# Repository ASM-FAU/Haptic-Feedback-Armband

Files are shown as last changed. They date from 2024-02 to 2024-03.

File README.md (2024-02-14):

# Haptic Feedback Armband

The haptic feedback armband was mainly designed for prosthesis appliacations. It contains 5 vibration motors, of which each can correspond to one finger. The device is completely wireless and contains a custom designed PCB, 1800 mAh lithium polymer battery, 5 vibration motors, an IMU to gather motion data and an FSR to measure armband tightness. All code and hardware models are provided in this repository to replicate the device.

## Software
The software is split into two parts for the client device (the haptic feedback armband) and a master PC that it communicates with. The architecture is shown in the follong Figure.
Ros_overview

## Hardware
The armband consists of 5 modules in total. A main module, containing the PCB, battery and senors as well as a vibration motor and smaller modules containing a vibration motor only. The casing was 3D printed using FDM and PLA filament. The flexible links were printed with TPU filament. This is how the armband looks like:
Armband_3D_View
main_module
sub_module

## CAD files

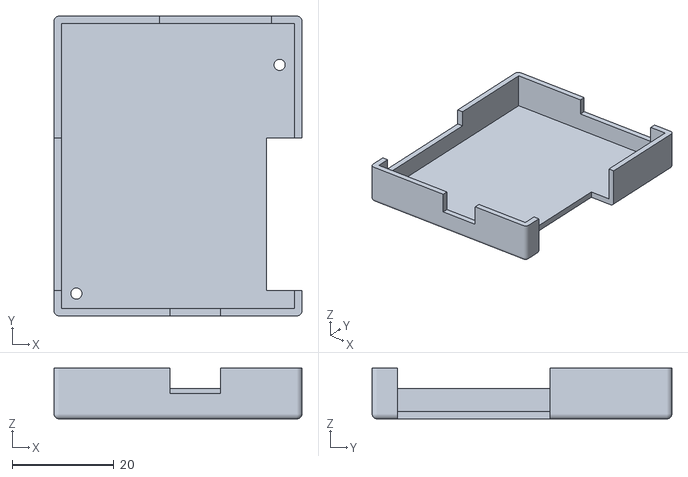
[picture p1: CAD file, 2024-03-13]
CAD/Main_Cover.stl
48.8 x 59.0 x 10.0

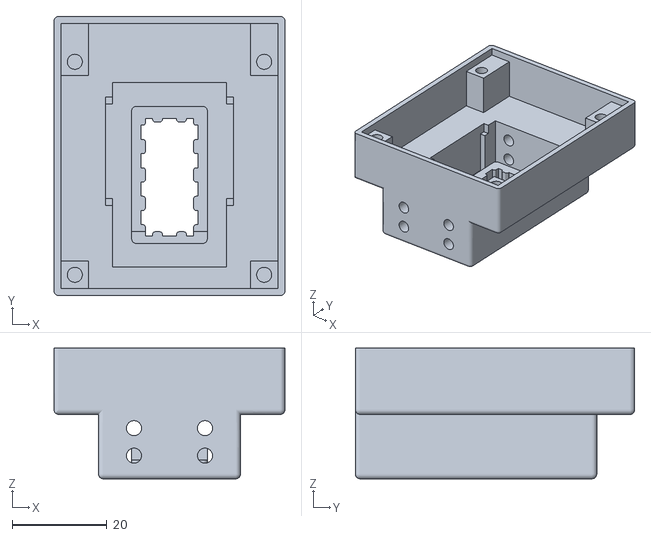
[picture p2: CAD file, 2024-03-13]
CAD/Main_Case.stl
48.8 x 59.0 x 27.6

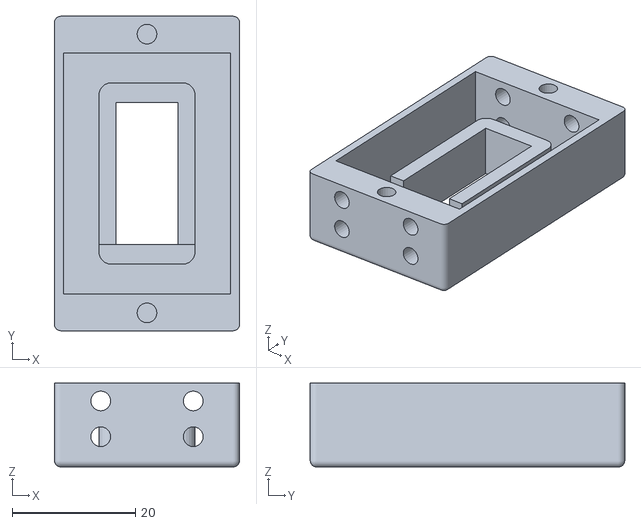
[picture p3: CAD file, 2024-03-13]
CAD/Sub_Case.stl
30.0 x 51.0 x 13.6

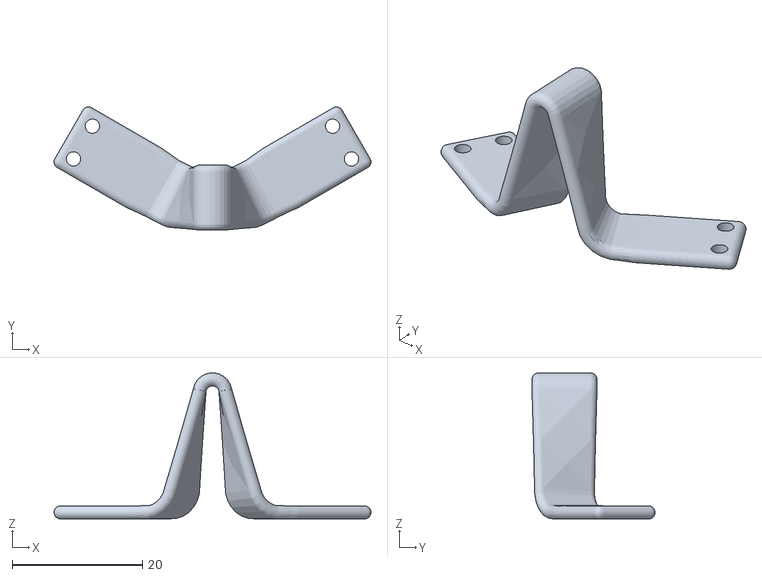
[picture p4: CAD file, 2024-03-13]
CAD/Link_Medium.stl
48.7 x 18.9 x 22.4

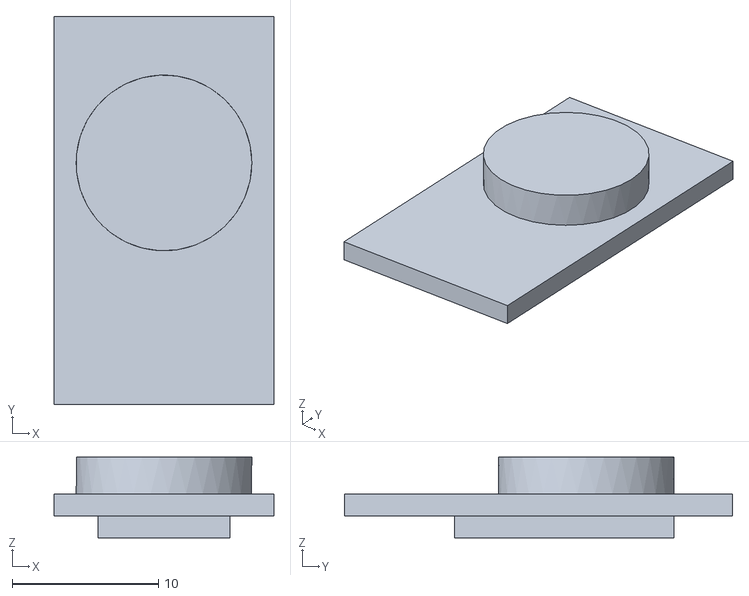
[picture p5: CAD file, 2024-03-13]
CAD/Force_Transmitter.stl
15.0 x 26.5 x 5.50

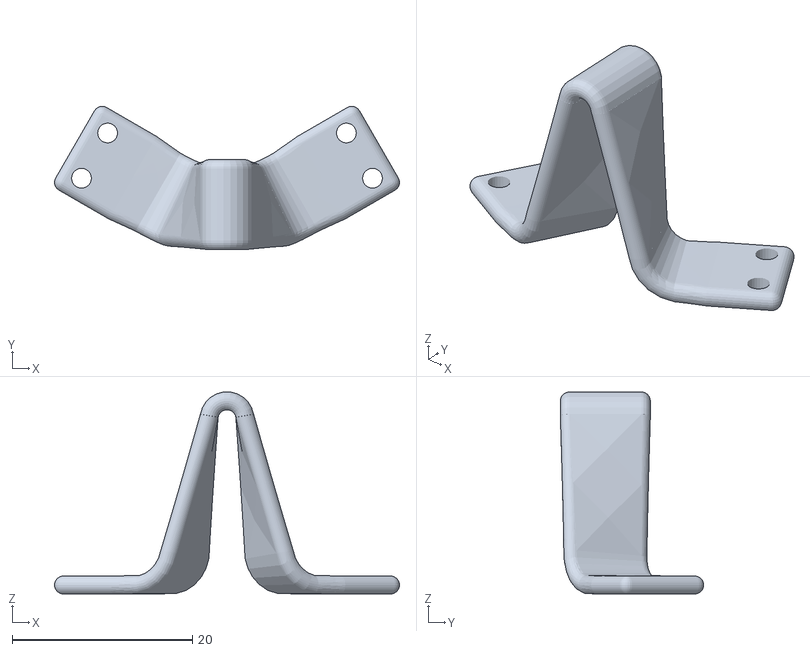
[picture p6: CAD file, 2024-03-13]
CAD/Link_Small.stl
38.3 x 15.9 x 22.4

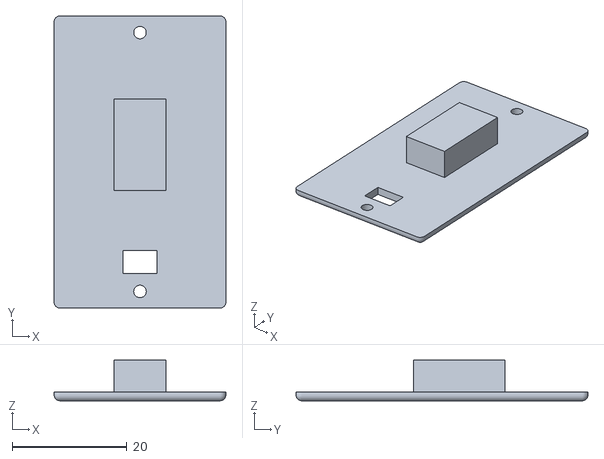
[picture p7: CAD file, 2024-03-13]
CAD/Sub_Cover.stl
30.0 x 51.0 x 7.10

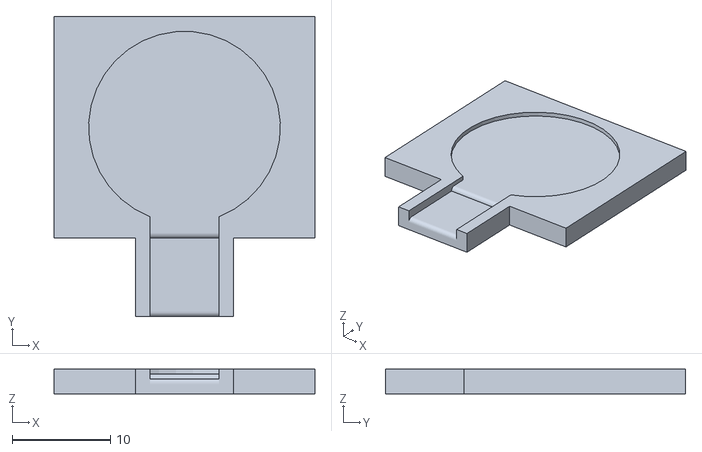
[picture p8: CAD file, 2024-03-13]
CAD/FSR_Support.stl
26.5 x 30.5 x 2.50

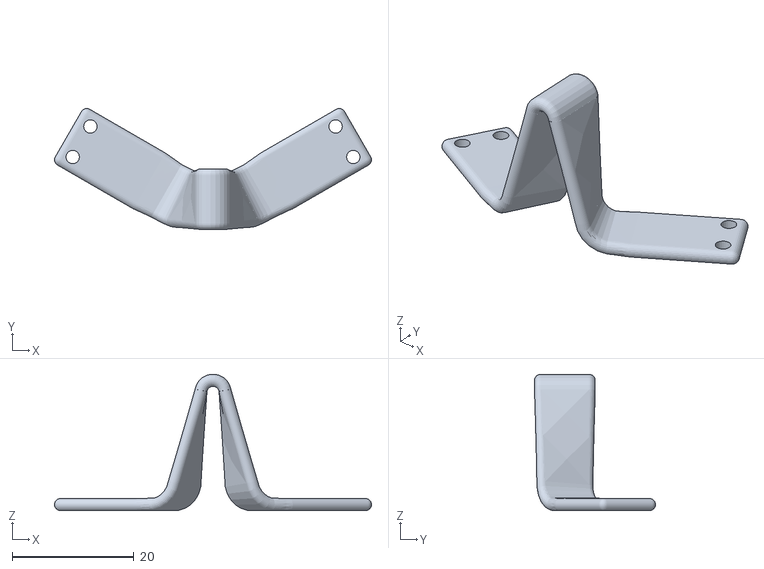
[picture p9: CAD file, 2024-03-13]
CAD/Link_Large.stl
52.2 x 19.9 x 22.4

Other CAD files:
CAD/Main_Module_Full.dwg
CAD/Sub_Module__Full.dwg
CAD/Link_Medium_Large.dwg
CAD/Link_Small.dwg

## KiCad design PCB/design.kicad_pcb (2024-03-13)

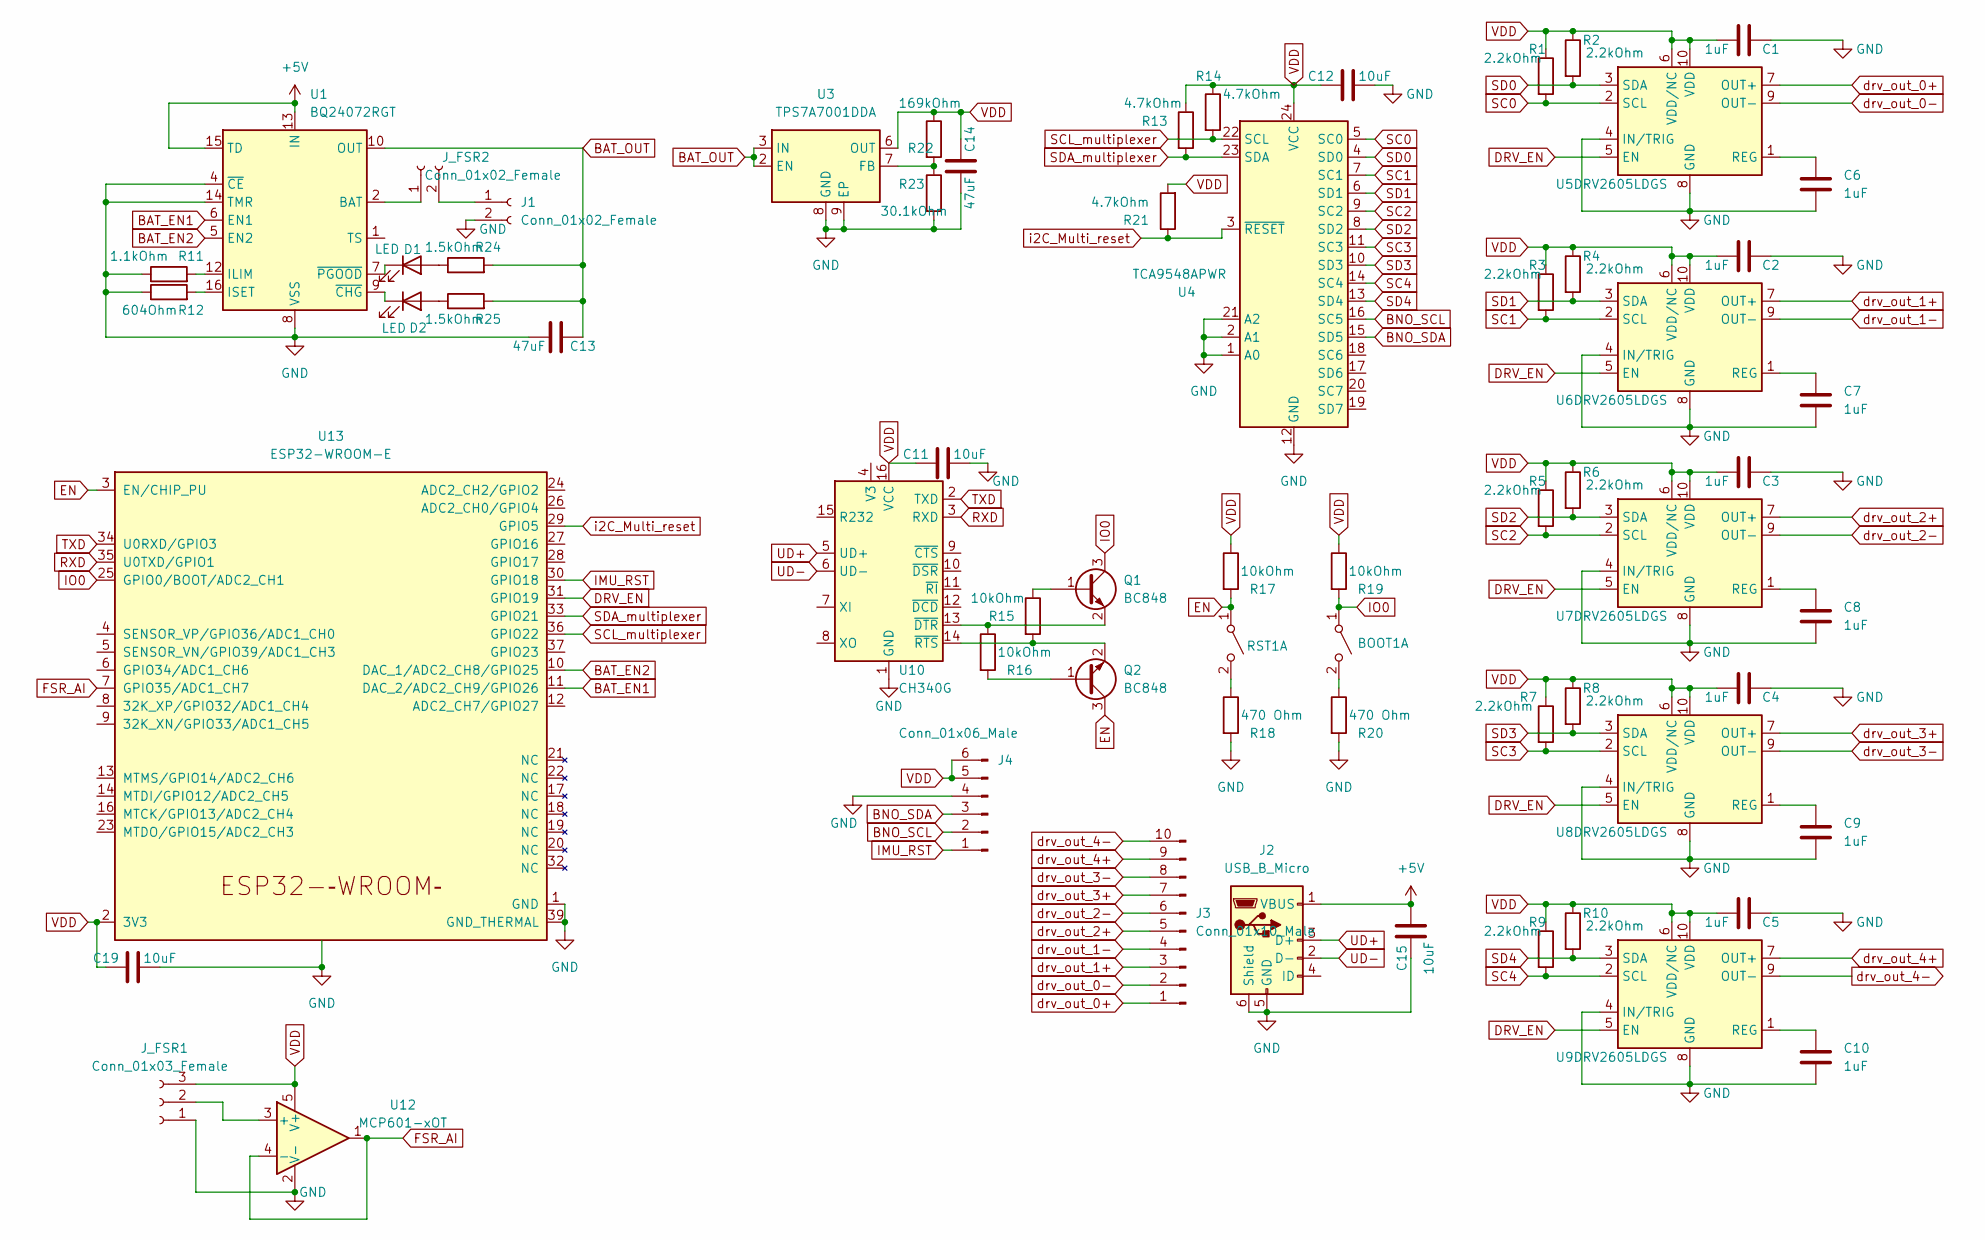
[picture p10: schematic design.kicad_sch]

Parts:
BOOT1: SW_DPST_x2; SW_SPST_B3U-1000P
C1, C2, C3, C4, C5, C6, C7, C8, C9, C10: 1uF; C_0402_1005Metric
C11, C12, C15, C19: 10uF; C_0402_1005Metric
C13, C14: 47uF; C_0805_2012Metric
D1, D2: LED; LED_0402_1005Metric
J1: Conn_01x02_Female; JST_PH_B2B-PH-K_1x02_P2.00mm_Vertical
J2: USB_B_Micro; USB_Micro-B_Amphenol_10118194_Horizontal
J3: Conn_01x10_Male; PinHeader_1x10_P2.54mm_Vertical
J4: Conn_01x06_Male; PinSocket_1x06_P2.54mm_Vertical
J_FSR1: Conn_01x03_Female; PinHeader_1x03_P2.54mm_Vertical
J_FSR2: Conn_01x02_Female; PinHeader_1x02_P2.54mm_Vertical
Q1, Q2: BC848; SOT-23
R1, R2, R3, R4, R5, R6, R7, R8, R9, R10: 2.2kOhm; R_0402_1005Metric
R11: 1.1kOhm; R_0402_1005Metric
R12: 604Ohm; R_0402_1005Metric
R13, R14, R21: 4.7kOhm; R_0402_1005Metric
R15, R16, R17, R19: 10kOhm; R_0402_1005Metric
R18, R20: 470 Ohm; R_0402_1005Metric
R22: 169kOhm; R_0402_1005Metric
R23: 30.1kOhm; R_0402_1005Metric
R24, R25: 1.5kOhm; R_0402_1005Metric
RST1: SW_DPST_x2; SW_SPST_B3U-1000P
U1: BQ24072RGT; VQFN-16-1EP_3x3mm_P0.5mm_EP1.6x1.6mm
U3: TPS7A7001DDA; TI_SO-PowerPAD-8_ThermalVias
U4: TCA9548APWR; TSSOP-24_4.4x7.8mm_P0.65mm
U5, U6, U7, U8, U9: DRV2605LDGS; VSSOP-10_3x3mm_P0.5mm
U10: CH340G; SOIC-16_3.9x9.9mm_P1.27mm
U12: MCP601-xOT; SOT-23-5
U13: ESP32-WROOM-E; ESP32-WROOM-32E

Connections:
+5V: C15.1, J2.1 (VBUS), U1.13 (IN), U1.15 (TD)
BAT_EN1: U1.6 (EN1), U13.11 (DAC_2/ADC2_CH9/GPIO26)
BAT_EN2: U1.5 (EN2), U13.10 (DAC_1/ADC2_CH8/GPIO25)
BAT_OUT: C13.2, R24.2, R25.2, U1.10 (OUT), U1.11 (OUT), U3.2 (EN), U3.3 (IN)
BNO_SCL: J4.2, U4.16 (SC5)
BNO_SDA: J4.3, U4.15 (SD5)
DRV_EN: U5.5 (EN), U6.5 (EN), U7.5 (EN), U8.5 (EN), U9.5 (EN), U13.31 (GPIO19)
EN: Q2.3 (C), R17.2, RST1.1 (A), U13.3 (EN/CHIP_PU)
FSR_AI: U12.1, U12.4 (-), U13.7 (GPIO35/ADC1_CH7)
GND: C1.2, C2.2, C3.2, C4.2, C5.2, C6.1, C7.1, C8.1, C9.1, C10.1, C11.1, C12.1, C13.1, C14.1, C15.2, C19.1, J1.2, J2.5 (GND), J2.6 (Shield), J4.4, J_FSR1.1, R11.1, R12.1, R18.2, R20.2, R23.2, U1.4 (~CE), U1.8 (VSS), U1.14 (TMR), U1.17 (VSS), U3.8 (GND), U3.9 (EP), U4.1 (A0), U4.2 (A1), U4.12 (GND), U4.21 (A2), U5.4 (IN/TRIG), U5.8 (GND), U6.4 (IN/TRIG), U6.8 (GND), U7.4 (IN/TRIG), U7.8 (GND), U8.4 (IN/TRIG), U8.8 (GND), U9.4 (IN/TRIG), U9.8 (GND), U10.1 (GND), U12.2 (V-), U13.1 (GND), U13.15 (GND), U13.38 (GND), U13.39 (GND_THERMAL)
IMU_RST: J4.1, U13.30 (GPIO18)
IO0: BOOT1.1 (A), Q1.3 (C), R19.2, U13.25 (GPIO0/BOOT/ADC2_CH1)
unnamed: BOOT1.2 (B), R20.1
unnamed: D1.2 (A), R24.1
unnamed: D1.1 (K), U1.7 (~PGOOD)
unnamed: D2.2 (A), R25.1
unnamed: D2.1 (K), U1.9 (~CHG)
unnamed: J1.1, J_FSR2.2
unnamed: J_FSR1.2, U12.3 (+)
unnamed: J_FSR2.1, U1.2 (BAT), U1.3 (BAT)
unnamed: Q1.1 (B), R15.1
unnamed: Q1.2 (E), R16.1, U10.13 (~DTR)
unnamed: Q2.1 (B), R16.2
unnamed: Q2.2 (E), R15.2, U10.14 (~RTS)
unnamed: R18.1, RST1.2 (B)
unnamed: R11.2, U1.12 (ILIM)
unnamed: R12.2, U1.16 (ISET)
unnamed: R22.2, R23.1, U3.7 (FB)
unnamed: C6.2, U5.1 (REG)
unnamed: C7.2, U6.1 (REG)
unnamed: C8.2, U7.1 (REG)
unnamed: C9.2, U8.1 (REG)
unnamed: C10.2, U9.1 (REG)
RXD: U10.2 (TXD), U13.34 (U0RXD/GPIO3)
SC0: R1.2, U4.5 (SC0), U5.2 (SCL)
SC1: R3.2, U4.7 (SC1), U6.2 (SCL)
SC2: R5.2, U4.9 (SC2), U7.2 (SCL)
SC3: R7.2, U4.11 (SC3), U8.2 (SCL)
SC4: R9.2, U4.14 (SC4), U9.2 (SCL)
SCL_multiplexer: R14.2, U4.22 (SCL), U13.36 (GPIO22)
SD0: R2.2, U4.4 (SD0), U5.3 (SDA)
SD1: R4.2, U4.6 (SD1), U6.3 (SDA)
SD2: R6.2, U4.8 (SD2), U7.3 (SDA)
SD3: R8.2, U4.10 (SD3), U8.3 (SDA)
SD4: R10.2, U4.13 (SD4), U9.3 (SDA)
SDA_multiplexer: R13.2, U4.23 (SDA), U13.33 (GPIO21)
TXD: U10.3 (RXD), U13.35 (U0TXD/GPIO1)
UD+: J2.3 (D+), U10.5 (UD+)
UD-: J2.2 (D-), U10.6 (UD-)
VDD: C1.1, C2.1, C3.1, C4.1, C5.1, C11.2, C12.2, C14.2, C19.2, J4.5, J4.6, J_FSR1.3, R1.1, R2.1, R3.1, R4.1, R5.1, R6.1, R7.1, R8.1, R9.1, R10.1, R13.1, R14.1, R17.1, R19.1, R21.2, R22.1, U3.6 (OUT), U4.24 (VCC), U5.6 (VDD/NC), U5.10 (VDD), U6.6 (VDD/NC), U6.10 (VDD), U7.6 (VDD/NC), U7.10 (VDD), U8.6 (VDD/NC), U8.10 (VDD), U9.6 (VDD/NC), U9.10 (VDD), U10.16 (VCC), U12.5 (V+), U13.2 (3V3)
drv_out_0+: J3.1, U5.7 (OUT+)
drv_out_0-: J3.2, U5.9 (OUT-)
drv_out_1+: J3.3, U6.7 (OUT+)
drv_out_1-: J3.4, U6.9 (OUT-)
drv_out_2+: J3.5, U7.7 (OUT+)
drv_out_2-: J3.6, U7.9 (OUT-)
drv_out_3+: J3.7, U8.7 (OUT+)
drv_out_3-: J3.8, U8.9 (OUT-)
drv_out_4+: J3.9, U9.7 (OUT+)
drv_out_4-: J3.10, U9.9 (OUT-)
i2C_Multi_reset: R21.1, U4.3 (~RESET), U13.29 (GPIO5)

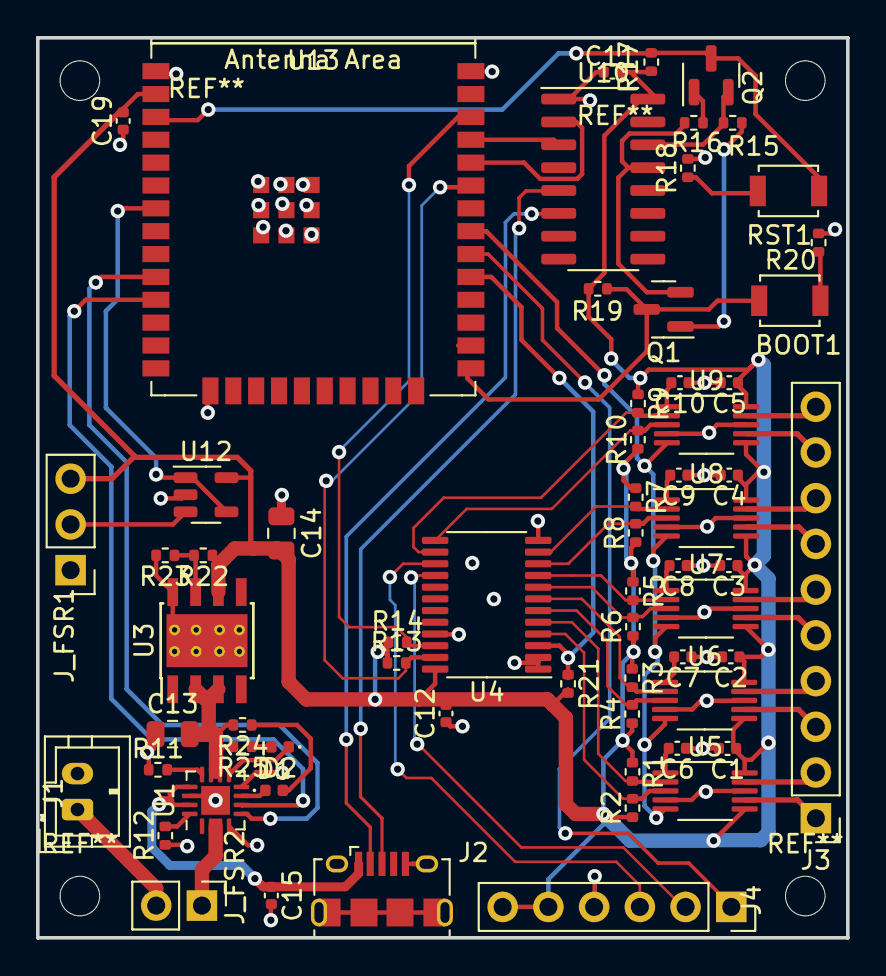
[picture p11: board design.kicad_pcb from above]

Board: 2 copper layers, 45.0 x 50.0 mm, 64 parts (0 on the bottom side), 61 nets.

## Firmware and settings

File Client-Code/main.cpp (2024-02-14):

#include <Arduino.h>
#include "WiFi.h"
#include "lwip/sockets.h"
#include "lwip/err.h"
#include "peripheral/i2c_multiplexer.hpp"
#include "service/communication.hpp"
#include "classes/tcp_socket_communication.hpp"
#include "peripheral/bno_imu.hpp"
#include <ArduinoJson.h>
#include "utils/log.hpp"
#include "peripheral/drv.hpp"
#include "AsyncElegantOTA.h"
#include <Wire.h>
#include "ESPAsyncWebServer.h"
#include "peripheral/battery_management.hpp"
#include "peripheral/force_sensor.hpp"
#include "freertos/semphr.h"
#include "FreeRTOS.h"
#include "freertos/task.h"


#define UPDATEINTERVAL_MS 20 //update interval in ms	
#define ENABLE_MULTITASKING 0 //set to 1 to enable multitasking else run in super-loop

#define WIFI_SSID "Debug Network"
#define WIFI_PASSWORT "1234567890"

#define HOST_IP_ADDR "192.168.43.226"//"192.168.178.31"//"192.168.178.44" //ip of the tcp master device
#define PORT 5000 //port of the tcp socket


TCP_Socket_Communication my_tcp_socket(PORT,HOST_IP_ADDR);
AsyncWebServer server(80);
SemaphoreHandle_t xMutex;


//declare functions
void handle_position_data(); 
void handle_haptic_feedback();
void handle_delay(long a);

void handle_position_data_task(void* pvParameters){//task to handle the position data. runns on the first core(0)
  while(1){
    long start_time=0;
    if(xSemaphoreTake(xMutex, portMAX_DELAY) == pdTRUE){//function to take the mutex if it is available
      start_time = millis();
      handle_position_data(); //function to handle the position data
      AsyncElegantOTA.loop(); //function to handle the ota update. needs to be called in the loop
      xSemaphoreGive(xMutex); //function to give the mutex back
    }
    vTaskDelay(20-(millis()-start_time)/portTICK_PERIOD_MS); //delay to run the task every 20ms->50Hz
  }
}

void handle_haptic_feedback_task(void* pvParameters){//task to handle the haptic feedback. runns on the second core(1)
  while(1){
    long start_time=0;
    if(xSemaphoreTake(xMutex, portMAX_DELAY) == pdTRUE){ //function to take the mutex if it is available
      start_time = millis();
      handle_haptic_feedback(); //function to handle the haptic feedback
      AsyncElegantOTA.loop(); //function to handle the ota update. needs to be called in the loop
      xSemaphoreGive(xMutex); //function to give the mutex back
    }
    vTaskDelay(20-(millis()-start_time)/portTICK_PERIOD_MS);//delay to run the task every 20ms->50Hz
  }
}

void init_pins(){
  pinMode(DRV_ENABLE_PIN,OUTPUT); //set the drv enable pin to output
  pinMode(BATTERY_MANAGEMENT_ENABLE_PIN_1,OUTPUT); //set the battery management enable pin 1 to output
  pinMode(BATTERY_MANAGEMENT_ENABLE_PIN_2,OUTPUT); //set the battery management enable pin 2 to output
}


void setup() {
  
  Serial.begin(115200); 

  log_init(LOG_LEVEL_INFO); //set log levels for all modules to info
  
  log_info("setup");

  init_pins(); //function to initialize the pins
  log_info("pins init done");
  
  i2c_multiplexer_init(); //function to initialize the i2c multiplexer
  log_info("i2c multiplexer init done");
  
  bno_imu_init(); //function to initialize the imu
  log_info("bno init done");

  drv_init(); //function to initialize the drv driver
  log_info("drvinit done");

  force_sensor_init(); //function to initialize the force sensor
  log_info("force sensor init done");

  battery_management_set_normal_charging(); //function to set the fast charging mode for the battery management
  log_info("battery set fast charging");

  
  communication_connect_wifi(WIFI_SSID,WIFI_PASSWORT); //function to connect to the wifi
  log_info("wifi connected");	
  log_info(String(WiFi.localIP().toString())+"");

  server.on("/", HTTP_GET, [](AsyncWebServerRequest *request){
    request->send(200, "text/plain", "OTA_Update for ESP_Haptic_Feedback");
  }); //function to set up the http server for ota updates
  AsyncElegantOTA.begin(&server); //function to set up the ota update
  server.begin(); //function to start the http server for ota updates
  Serial.println("HTTP server started");

  my_tcp_socket.tcp_socket_init(); //function to initialize the tcp socket
  while(my_tcp_socket.tcp_socket_connect()!=0){ //function to connect to the tcp master device
    vTaskDelay(1000/portTICK_PERIOD_MS);
  }
  log_info("tcp connected");
  if(ENABLE_MULTITASKING==1){
    xMutex = xSemaphoreCreateMutex(); //function to create a mutex used by the parallel tasks
    //xTaskCreatePinnedToCore(handle_position_data_task, "handle_position_data_task", 10000, NULL, 1, NULL, 1); //function to create a task for handling the position data
    xTaskCreatePinnedToCore(handle_haptic_feedback_task, "handle_haptic_feedback_task", 10000, NULL, 1, NULL, 0); //function to create a task for handling the haptic feedback
    delay(1000);
  }
  
}


void loop() {
  if(ENABLE_MULTITASKING==0){//execute the following code in a super-loop
    long start_time = millis();
    //handle_position_data();  only activate if imu is connected
    handle_haptic_feedback();
    //Serial.println(force_sensor_read(), 2);
    AsyncElegantOTA.loop(); //function to handle the ota update. needs to be called in the loop
    handle_delay(start_time);
  }
}



/**
 * @brief Function for delaying the loop to get the desired update interval of 20 ms. If the loop takes longer than 20 ms, the delay is skipped. 
 * @param a time when the loop started
 */
void handle_delay(long a){
  //log_info(String("time needed for loop: ")+String(millis()-a));
  int delay_time = UPDATEINTERVAL_MS-(millis()-a);
  if (delay_time>0){
    vTaskDelay(delay_time/portTICK_PERIOD_MS);
  }
}


/**
 * @brief Function for dealing with the process for getting data from the imu to the master
 * 
 */
void handle_position_data(){
  //long a=millis();
  char p[TCP_SOCKET_SEND_SIZE];
  bno_imu_get_sensor_data_struct_char(p);//get orientation and acceleration data formatted as json string from the imu
  if(strlen(p)<=1){ //if no data is received or imu couldnt be initialized/found, skip round
    log_error("data couldnt be read for the bn055"); 
    return;
  }
  log_debug(p);
  if(my_tcp_socket.tcp_socket_send_string(p,sizeof(p))==TCP_SOCKET_SEND_SIZE){ //send data to the master, success if the size of the data is equal to the bits send
    //log_info("successful sent and collected data in ms: "+ String(millis()-a));
  }else{
    //could handle error here, else just skip round
  }
  
}

/**
 * @brief Function for dealing with the process for getting data from ther master to the drv driver
 * 
 */
void handle_haptic_feedback(){
  //long a=millis();
  char buff[TCP_SOCKET_READ_SIZE]; //including zero ending char
  strcpy(buff,my_tcp_socket.tcp_socket_receive_string_non_blocking());//non blocking mode -> no message skip round
  if(strlen(buff)<=1){
    //log_trace("no new data");//can skip input msg for debugging possible
    return;
  }else{
    log_info(buff);
    
    StaticJsonDocument<400> doc; 
    DeserializationError error = deserializeJson(doc,buff);//deserialize json string to json object
    // Empyt Input error when no msg received  ;  Invalid Input error when json String not complete
    if(error){
      log_error(error.f_str());
      return;
    }else{
      uint8_t drv_data_arr[5]; //array for the data for the drv driver
      for(uint8_t i=0;i<DRV_DEVICE_COUNTER;i++){
        drv_data_arr[i]=doc[String(i)];//read the data for each drv device from the json object
        drv_run_realtime(i,drv_data_arr[i]); //call the function to run the drv driver with the given intensity
        log_trace(String(drv_data_arr[i]));
      }
      //log_info("successful received data in ms: "+ String(millis()-a));
    }
  }
}
